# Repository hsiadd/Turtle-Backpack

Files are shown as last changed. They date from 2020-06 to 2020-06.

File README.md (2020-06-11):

# Turtle-Backpack

Project Goals:  

1. Design micro sensor platform for logging turtle movement and environmental conditions in situ.
2. Develop tools for the analysis of data collected from this platform. 

What's here:

1. Source code
1. PCB Design Files
1. 3D Printer design files
1. R Modeling and Analysis Scripts

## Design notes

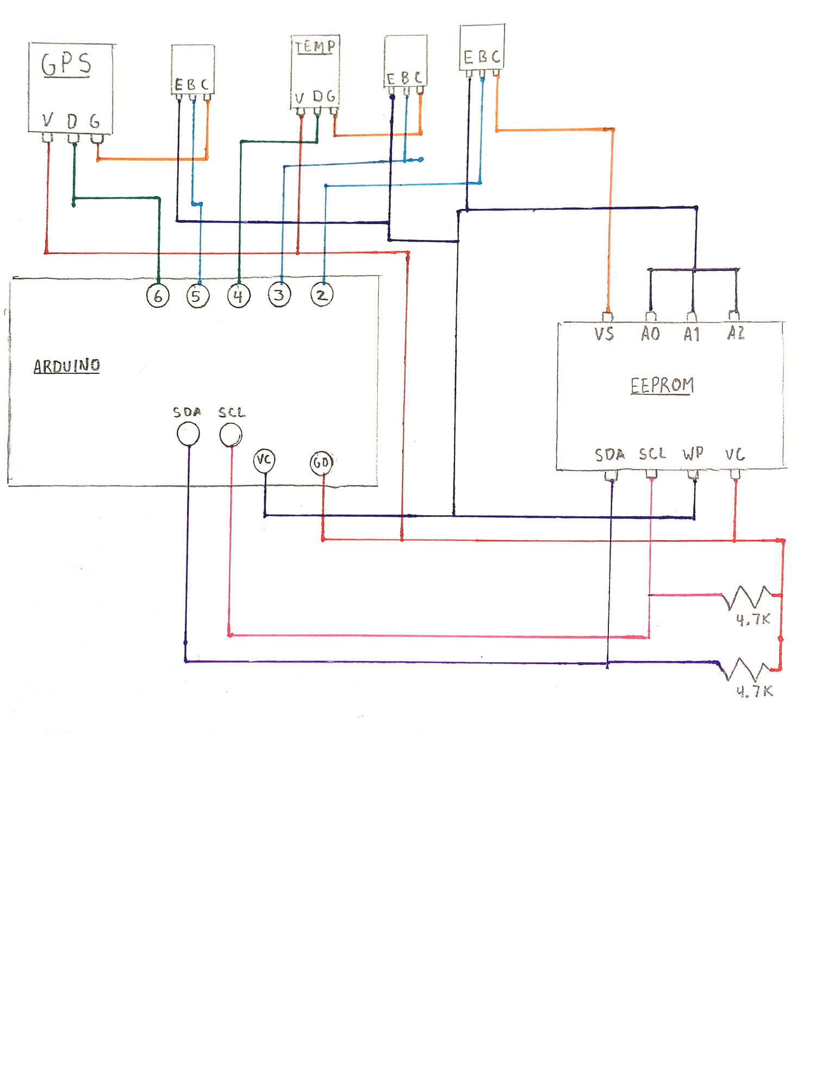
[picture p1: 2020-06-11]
PCB Designs/TNG 3.0/Full Circuit Sketch.jpg

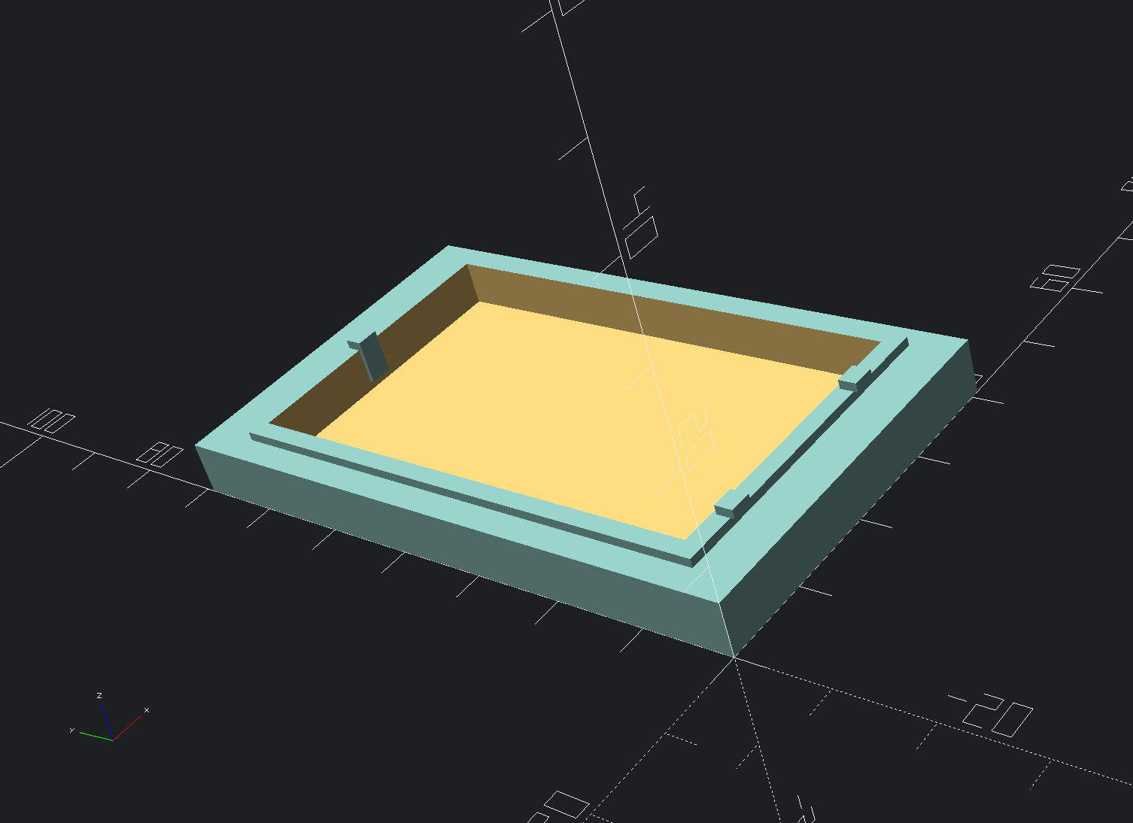
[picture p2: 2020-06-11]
Enclosure Designs/TOS V1/tos_bottom_3.png

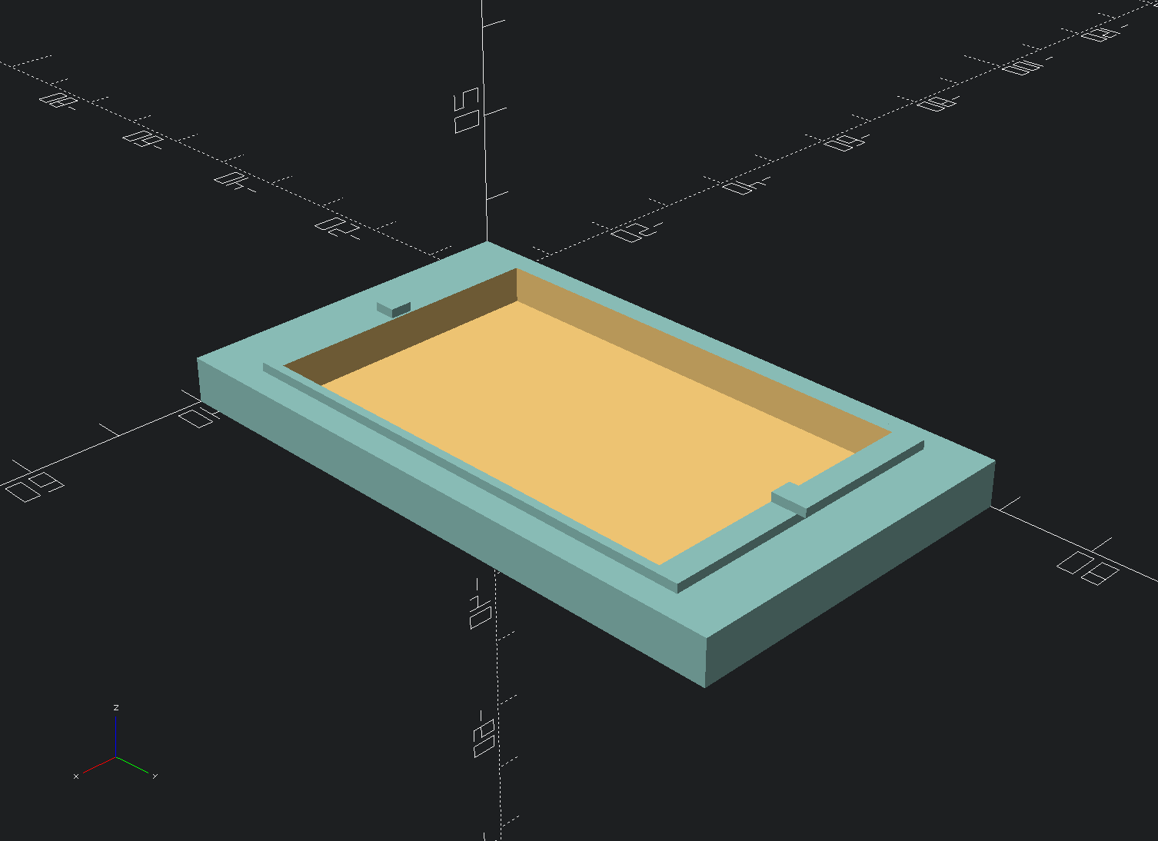
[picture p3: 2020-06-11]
Enclosure Designs/TOS V1/tos_bottom_2.png

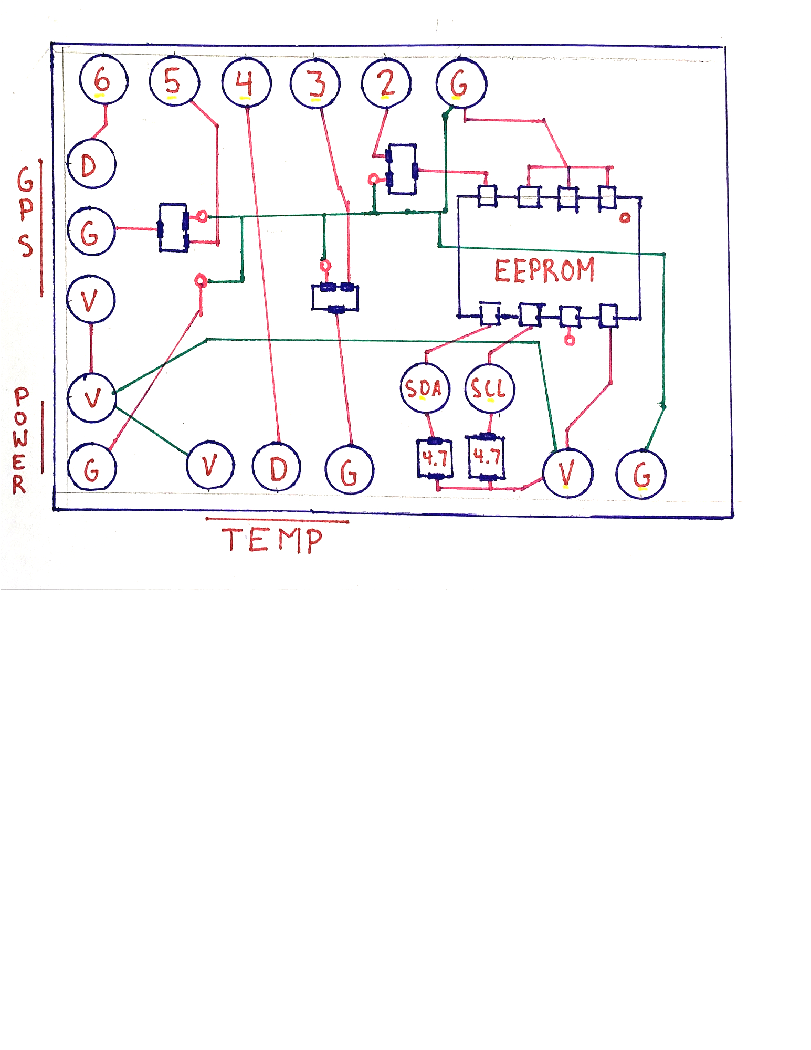
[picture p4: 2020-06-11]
PCB Designs/TNG 3.0/PCB Sketch.jpg

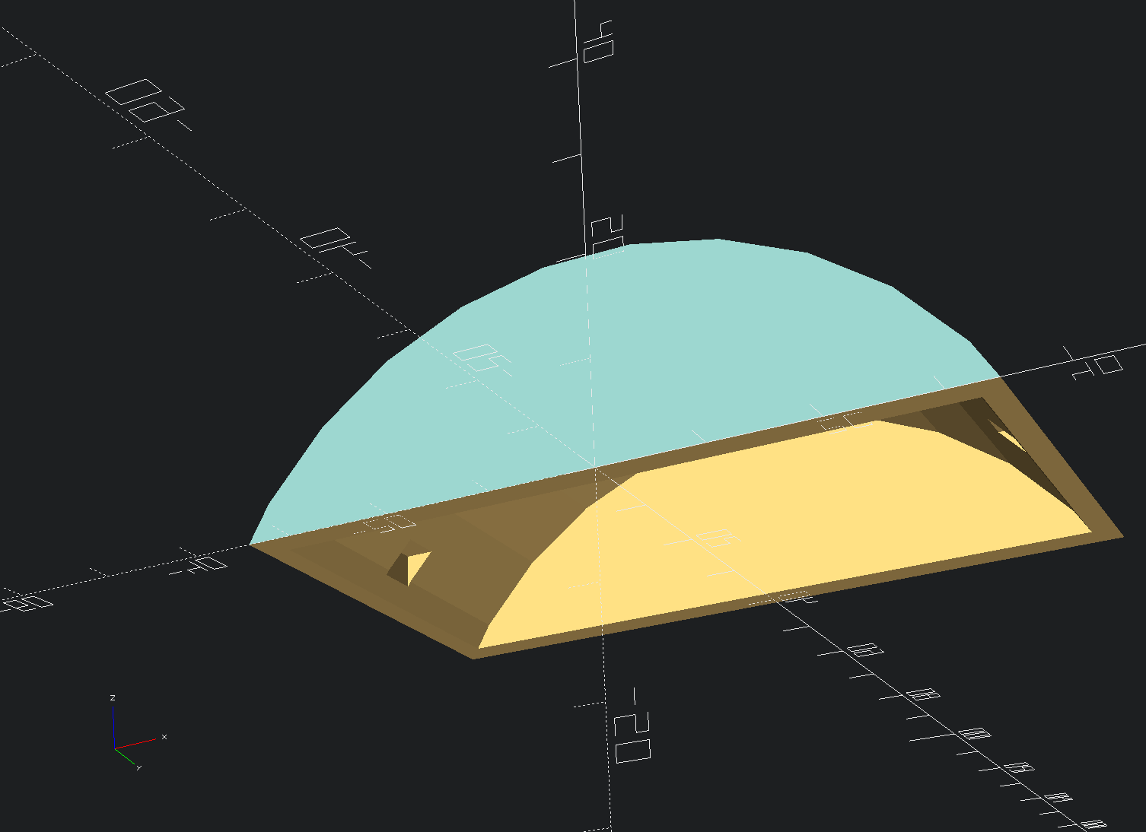
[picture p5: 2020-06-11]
Enclosure Designs/TOS V1/tos_top_2.png

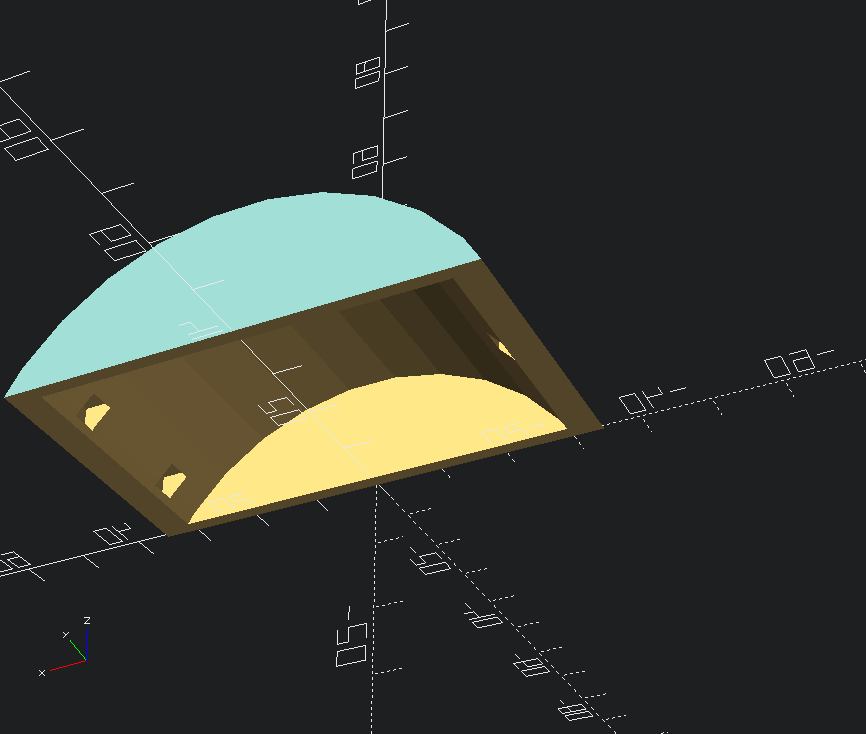
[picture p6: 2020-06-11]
Enclosure Designs/TOS V1/tos_top_3.png

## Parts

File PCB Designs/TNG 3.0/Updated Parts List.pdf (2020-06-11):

Part | Link | Price
Arduino Pro Mini 3.3V | https://www.sparkfun.com/products/11114 (https://www.sparkfun.com/products/11114) | $9.95
GP-20U7 GPS Receiver | https://www.sparkfun.com/products/13740 (https://www.sparkfun.com/products/13740) | $17.95
DS18B20 1-Wire Digital Temperature Sensor | https://www.sparkfun.com/products/245 (https://www.sparkfun.com/products/245) | $3.95
(2x) ZXTN25012EFHTA NPN Surface Mount Transistor | https://www.digikey.com/product-detail/en/diodes-incorporated/ZXTN25012EFHTA/ZXTN25012EFHTADICT-ND/1 137303 (https://www.digikey.com/product-detail/en/diodes-incorporated/ZXTN25012EFHTA/ZXTN25012EFHTADICT-ND/1137303) | $0.61
(2x) Surface Mount 4.7k Resistor | I haven’t looked into sourcing these / what the right packaging is
24LC256 I²C EEPROM (8-SOIC) | https://www.digikey.com/product-detail/en/24LC256-I%2fSN/24LC256-I%2fSN-ND/440169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 ZMyIsInQiOiJGdURGM3RYR3hZ Z0hIQUhjTTlsQnEwekZHcVJ5blJ TRXdpdGEyb0lvYnkyblI3M3hBSj l4QU1UQzBSZ0JJNUJRVkFMUE 52WmI5THNUT3BRTkRRTnpQR VhhRWhIK3BiTERONG0xSVpad W83bnc0WkpOZlFYWk03a2Q2Z HU4YldRTyJ9 (https://www.digikey.com/product-detail/en/24LC256-I%2fSN/24LC256-I%2fSN-ND/440169?so=61272664) | $0.76
400 mAh Lithium Ion Battery | https://www.sparkfun.com/products/13851 (https://www.sparkfun.com/products/13851) | $4.95
JST Right-Angle Connector (Through-Hole 2-Pin) | https://www.sparkfun.com/products/9749 (https://www.sparkfun.com/products/9749) | $.095
JST Right-Angle Connector (Through-Hole 3-Pin) | https://www.sparkfun.com/products/9750 (https://www.sparkfun.com/products/9750) | $0.95

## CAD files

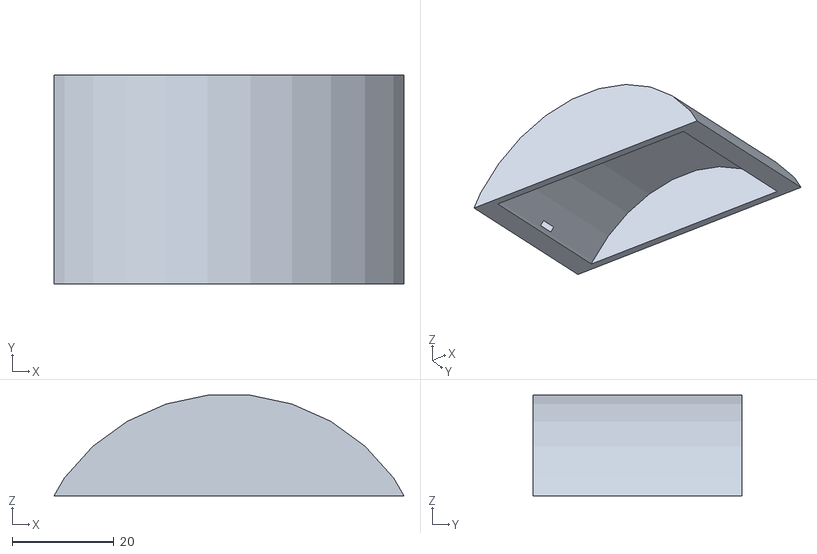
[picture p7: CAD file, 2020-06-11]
Enclosure Designs/TOS V1/tos_top_2.stl
68.8 x 41.0 x 19.8

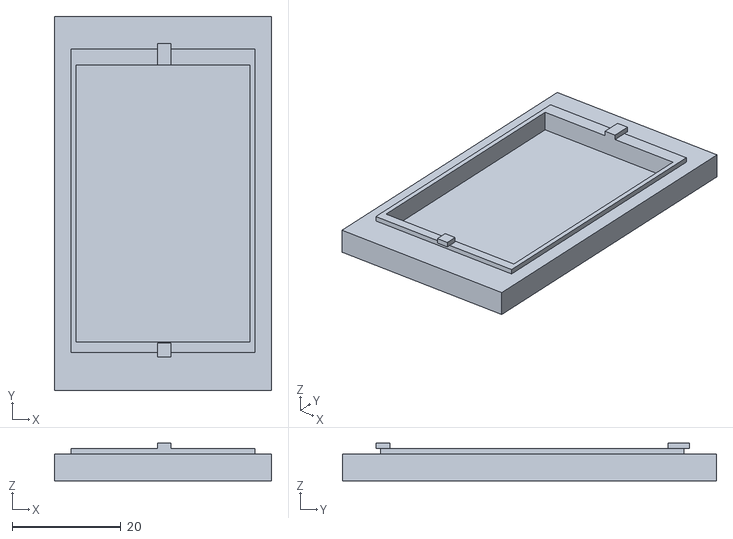
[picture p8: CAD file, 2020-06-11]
Enclosure Designs/TOS V1/tos_bottom_2.stl
40.0 x 69.0 x 7.00

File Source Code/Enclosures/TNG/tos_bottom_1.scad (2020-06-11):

/*
    TOS Version 1 Bottom
    

*/

//Body
cube([40,69,3]);

// Clasp front
difference() {
    translate([19.0,6.5,0]) {
        cube([2.5,5,5]);
    };
    translate([19.0,6,0]) {
        cube([5,1,4]);
    }    
}

// Clasp back
difference() {
    translate([19.0,56.5,0]) {
        cube([2.5,5,5]);
    };
    translate([19.0,61,0]) {
        cube([5,1,4]);
    }    
}

// Clasp left
/*
difference() {
    translate([2.0,32.5,0]) {
        cube([2.5,4,5]);
    };
    translate([0,32.5,-1]) {
        cube([2.5,4,5]);
    }    
}
*/




//Lip
difference() {
    translate([2.5,7,0]) {
            cube([35, 54, 4]);
    }

    translate([3.5,9,0]) {
            cube([33, 51, 4]);
    }
}

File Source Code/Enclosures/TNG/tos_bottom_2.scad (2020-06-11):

/*
    TOS Version 2 Bottom
    

*/

//Body
difference() {
    cube([40,69,5]);
    translate([3.5,9,2]) {
            cube([33, 51, 4]);
    }    
}

// Clasp front
difference() {
    translate([19.0,6.25,2]) {
        cube([2.5,2.5,5]);
    };
    translate([19.0,6,0]) {
        cube([5,1,6]);
    }    
}

// Clasp back
difference() {
    translate([19.0,60.0,2]) {
        cube([2.5,4,5]);
    };
    translate([19.0,63,0]) {
        cube([5,1,6]);
    }    
}

// Clasp left
/*
difference() {
    translate([2.0,32.5,0]) {
        cube([2.5,4,5]);
    };
    translate([0,32.5,-1]) {
        cube([2.5,4,5]);
    }    
}
*/




//Lip
difference() {
    translate([3,7,2]) {
            cube([34, 56, 4]);
    }

    translate([4,9,2]) {
            cube([32, 51, 4]);
    }
}

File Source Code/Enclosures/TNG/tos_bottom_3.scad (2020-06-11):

/*
    TOS Version 3 Bottom
    

*/

//Body
difference() {
    cube([41,69,6]);
    translate([5,7,2]) {
            cube([32, 55, 5]);
    }    
}

// Clasp front left
difference() {
    translate([9.0,4.5,3]) {
        cube([2.5,2,5]);
    };
    translate([9.0,4.0,0]) {
        cube([5,1,7]);
    }

    
}


 
// Clasp front right
difference() {
    translate([29.0,4.5,3]) {
        cube([2.5,2,5]);
    };
    translate([29.0,4,0]) {
        cube([5,1,7]);
    }
    
}


// Clasp back
difference() {
    translate([19.0,61.5,3]) {
        cube([2.5,2.0,5]);
    };
    translate([19.0,63,0]) {
        cube([5,1,7]);
    }    
}



//Lip
difference() {
    translate([3,5,3]) {
            cube([35.5, 58, 4]);
    }

    translate([5,7,3]) {
            cube([32, 55, 4]);
    }
}

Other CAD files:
Source Code/Enclosures/TNG/tos_top_1.scad
Source Code/Enclosures/TNG/tos_top_2.scad
Source Code/Enclosures/TNG/tos_top_3.scad

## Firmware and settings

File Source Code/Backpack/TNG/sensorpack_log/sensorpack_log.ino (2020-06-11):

/****************************************************************************************************************************
 * GEN 3 Sensor Pack Logger with GPS and Temperature Sensor
 * Last updated May 13, 2020 by Luke Stuntz
 * 
 * REMOVE BATTERY BEFORE PLUGGING INTO COMPUTER
 ************************************************************************************************************************/


// First we include the libraries
#include <OneWire.h> 
#include <DallasTemperature.h>
#include <TinyGPS++.h>    
#include <LowPower.h> 
#include <SoftwareSerial.h>
#include <Wire.h>
#include <eepromi2c.h> 

/*******************( Case Specific Variables )***********************/

// how long will GPS receiver stay on at max?
int stay_on = 2 ; /*minutes*/

// how long is the data logging interval? (time between readings)
float logger_interval = 10; /*minutes*/

// how many GPS points do you want to take for max accuracy?
int fixes = 4 ;

/*******************( Defining pins )*****************/
#define temp_feed 2
#define gps_feed 3
#define transistor_eeprom 4
#define transistor_gps 5
#define transistor_temp 6
#define empty_pin 7

/****************( Creating Operational Variables )********************/
uint32_t feedDuration = stay_on * 60000;
uint32_t sleepInterval = (logger_interval * 60) / 8;
unsigned short address; //EEPROM adress
unsigned short address_location = 3999; 
uint32_t GPS_run = millis(), timer = millis();

// This is what all the data will be recorded in while reading from GPS and temperature sensor and writing to EEPROM
struct config {
  byte log_attempt;
  byte fixes;
  double lat;
  double lon;
  byte day;
  byte month;
  byte hour;
  byte minute;
  uint32_t sats;
  double temp;
} config;

/****************( Library specific object setups )********************/
TinyGPSPlus gps;

SoftwareSerial ss(gps_feed, empty_pin);

OneWire oneWire(temp_feed); 

DallasTemperature sensors(&oneWire);

/**********************( Functions )**************************/ 

// Runs GPS
bool feedGPS() {
    while (ss.available()) {
      if (gps.encode(ss.read()))
        return true;
        }
    return false;
}

// This is essentially a convoluted function to throw out GPS locations that are blatantly wrong
// During GPS sampling, multiple points are recorded
// If one point deviates from the mean more than twice the standard deviation, it is thrown out
// THIS IS NOT CURRENTLY USED - Has been succesfully integrated into past versions and is important to ensure elimination of significant errors
// Check to see the impact of including this function on battery life 
double outlying(double FixLats[], int points){
  double TrueLats[points];
  double sum = 0;
  double devsum = 0;
  double finalsum = 0;
    for (int i = 0; i < points; i++){
      sum += FixLats[i];
    }
    for (int i = 0; i < points; i++){
      double oavg = (sum - FixLats[i]) / (points - 1);
      devsum = 0;
      for (int g = 0; g < points; g++){
        double odev = abs(FixLats[g] - oavg);
        devsum += odev;
      }
      double stdev = devsum / points;
      if (abs(FixLats[i] - oavg) > 2 * stdev){
        TrueLats[i] = oavg;
      }
      else {
        TrueLats[i] = FixLats[i];
      }
    }
  for (int i = 0; i < points; i++){
    finalsum += TrueLats[i];
  }
  double fixedavg = finalsum / points;
  return fixedavg;
}

// Prints data to serial monitor when recorded
void printLocation() {

        Serial.print(config.fixes); Serial.print(",");
        Serial.print(config.sats); Serial.print(",");
        Serial.print(config.lat,6); Serial.print(",");
        Serial.print(config.lon,6); Serial.print(",");
        Serial.print(config.day); Serial.print("/");
        Serial.print(config.month);Serial.print(",");
        if (config.hour < 10) Serial.print("0");
        Serial.print(config.hour); Serial.print(":");
        if (config.minute < 10) Serial.print("0");
        Serial.print(config.minute);Serial.print(",");
        Serial.println(config.temp);
        delay(10);  
}

/**********************( Setup )**************************/ 

void setup() 
{ 
 // start serial port 
 Serial.begin(9600);
 ss.begin(9600);
 Wire.begin();

 Serial.println("Starting up Luke's sensor pack..."); 

 // Set transistor operating pins to output
 pinMode(transistor_eeprom, OUTPUT);
 pinMode(transistor_gps, OUTPUT);
 pinMode(transistor_temp, OUTPUT);
 pinMode(LED_BUILTIN, OUTPUT);

 for (int i = 0; i < 3; i++) {
        digitalWrite(LED_BUILTIN, HIGH);
        delay(400);
        digitalWrite(LED_BUILTIN, LOW);
        delay(400);
        }

 // Initialize EEPROM
 digitalWrite(transistor_eeprom, HIGH);
 eeRead(address_location, address);
 delay(10);
 digitalWrite(transistor_eeprom, LOW);

 // Blink three times to show that the unit has been setup
 for (int i = 0; i < 3; i++) {
        digitalWrite(LED_BUILTIN, HIGH);
        delay(1000);
        digitalWrite(LED_BUILTIN, LOW);
        delay(1000);
        }
}

/**************************( Loop )*******************************/
void loop() 
{ 

  Serial.println("Beginning data request...");

  digitalWrite(transistor_gps, HIGH);

  delay(1000);

  config.sats = 0;
  GPS_run = millis();
  int locs = 0;
  double RoughLats[fixes];
  double RoughLons[fixes];

  // Collect GPS Points and Number of Satellites
  while (millis() - GPS_run < feedDuration && locs < fixes){
      feedGPS();
      if (gps.location.isUpdated()){
        RoughLats[locs] = gps.location.lat();
        RoughLons[locs] = gps.location.lng();
        locs++ ;       
        config.sats = config.sats + gps.satellites.value();
        delay(5000);
        }  
    }  

  // Write data to config
  config.log_attempt = 1; 
  config.fixes = locs;
  config.lat = outlying(RoughLats, locs);
  config.lon = outlying(RoughLons, locs);
  config.day = gps.date.day();
  config.month = gps.date.month();
  config.hour = gps.time.hour();
  config.minute = gps.time.minute();
    
  digitalWrite(transistor_gps, LOW);

  // Collect temperature
  digitalWrite(transistor_temp, HIGH);
  delay(1000);
  sensors.requestTemperatures();
  config.temp = sensors.getTempCByIndex(0);
  delay(1000);
  digitalWrite(transistor_temp, LOW);

  delay(200);

  printLocation();

  delay(200);

  // Write data to EEPROM
  digitalWrite(transistor_eeprom, HIGH);
  delay(10);
  eeWrite(address,config);
  address += sizeof(config);
  eeWrite(address_location, address);
  delay(100);
  digitalWrite(transistor_eeprom, LOW);

  // Blinks mean point taken
  for (int i = 0; i < 3; i++) {
        digitalWrite(LED_BUILTIN, HIGH);
        delay(400);
        digitalWrite(LED_BUILTIN, LOW);
        delay(400);
        }

  // Sleep
  for (int i = 0; i < sleepInterval; i++){
      LowPower.powerDown(SLEEP_8S, ADC_OFF, BOD_OFF);
      } 
} 

/********************************************************************/

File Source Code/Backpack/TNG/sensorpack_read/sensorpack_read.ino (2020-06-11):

/****************************************************************************************************************************
 * GEN 3 Sensor Pack Reader
 * Last updated May 13, 2020 by Luke Stuntz
 * 
 * REMOVE BATTERY BEFORE PLUGGING INTO COMPUTER
 * 
 * Read data into serial monitor by entering 'R'
 * This data can then be easily copied into a .txt file for conversion to .csv (or directly converted to .csv through delimination in Excel)
 * This could be improved by writing code to directly output a .csv
 * 
 * Clear data on sensor pack by entering 'C'
 ************************************************************************************************************************/

// First we include the libraries
#include <Wire.h>
#include <eepromi2c.h>

/*******************( Defining pins )*****************/
#define transistor_eeprom 4
#define transistor_gps 5
#define transistor_temp 6

/****************( Creating Operational Variables )********************/

// This is what all data will be stored in while reading from EEPROM to serial monitor
struct config {
  byte log_attempt;
  byte fixes;
  uint32_t sats;
  double lat;
  double lon;
  byte day;
  byte month;
  byte hour;
  byte minute;
  double temp;
  double a = 0;
  double b = 0;
  byte c = 0;
  byte d = 0;
} config;

unsigned short address_temp;
int address;

// used in Z case. Force prints x number of lines.
int numberLines = 25;  

/**********************( Functions )**************************/ 
// This prints the data to the serial monitor
void printLocation() {
        Serial.print(config.fixes); Serial.print(",");
        Serial.print(config.sats); Serial.print(",");
        Serial.print(config.lat,6); Serial.print(",");
        Serial.print(config.lon,6); Serial.print(",");
        Serial.print(config.day); Serial.print(",");
        Serial.print(config.month);Serial.print(",");
        if (config.hour < 10) Serial.print("0");
        Serial.print(config.hour); Serial.print(",");
        if (config.minute < 10) Serial.print("0");
        Serial.print(config.minute);Serial.print(",");
        Serial.println(config.temp, 4);
        delay(10);  
}

// This prints the menu of options
void menu() {
  Serial.println("___________MENU___________");
  Serial.println("Please type:");
  Serial.println("C - clear memory");
  Serial.println("R - Read locations (Reads each location)");
  Serial.print("Z - force print the first "); Serial.print(numberLines);Serial.println(" lines");
}

/**********************( Setup )**************************/ 
void setup(){
  
    Serial.begin(9600);
    Wire.begin();

    pinMode(transistor_eeprom, OUTPUT);
    pinMode(transistor_gps, OUTPUT);
    pinMode(transistor_temp, OUTPUT);
    pinMode(LED_BUILTIN, OUTPUT);
    digitalWrite(transistor_eeprom, HIGH); 
    digitalWrite(transistor_gps, LOW); 
    digitalWrite(transistor_temp, LOW);

    
    // blinks fast means read/clear sketch is loaded
    for (int i = 0; i < 5; i++) {
        digitalWrite(LED_BUILTIN, HIGH);
        delay(250);
        digitalWrite(LED_BUILTIN, LOW);
        delay(250);
        }

    menu();
}

/**************************( Loop )*******************************/
void loop(){

    if (Serial.available() == 1) {
      switch (toUpperCase(Serial.read())) {
        
        /************************* reads EEPROM *********************/
        case 'R':{
          digitalWrite(LED_BUILTIN, HIGH);
          
         // Reset flag and start address
          int x = 0; address = 0;

          Serial.println();
          Serial.println("************* COPY Begin *****************");
          Serial.println("Fixes,Total Sats,Lat,Lon,Day,Month,Hour,Minute,Temperature");

          while (x == 0) {
            eeRead(address, config);    //Read the first location into structure 'config'
            delay(1000);

            if (config.log_attempt == 0) {
              Serial.println();
              Serial.println("No more locations were recorded");
              Serial.println();
              x = 1;
            }
  
            else {
                printLocation(); 
              }

            address += sizeof(config);
            delay(5);
            }

          digitalWrite(LED_BUILTIN, LOW);
          Serial.println("************* Finished *****************"); Serial.println();
          menu();
        }   
        break;

        /****** clears EEPROM by writing a '0' to each address *******/
        case 'C':{ 
          digitalWrite(LED_BUILTIN, HIGH);

          Serial.println("");
          Serial.println("--------Clearing I2C EEPROM--------");
          Serial.print("Pleast wait until light turns off...");
  
          for (int i = 0; i < 4000; i++) {
            eeWrite(i, 0); delay(6);
          }
          
          Serial.println("Done"); 
          Serial.println("---------Done Clearing---------");
          digitalWrite(LED_BUILTIN, LOW); Serial.println();
          menu(); 
        }
        break;
         /*---------------------------------------------------------------*/

         /********************** for testing (force prints X lines of memory) *****************************/
        case 'Z':{ 
          digitalWrite(LED_BUILTIN, HIGH);

          eeRead(3999, address_temp);

          address = 0;
          Serial.println("************* Begin *****************");          
          for (int i = 0 ; i < numberLines; i++){
            eeRead(address, config); delay(100);
            printLocation(); 
            address += sizeof(config); 
          }


          Serial.print("Last address: ");Serial.println(address_temp);
          digitalWrite(LED_BUILTIN, LOW); 
          Serial.println("************* End *****************");
          Serial.println();
          menu(); 
        }
        break;
        /*---------------------------------------------------------------*/

        default:
          menu();
        break;
      }
    }
}
